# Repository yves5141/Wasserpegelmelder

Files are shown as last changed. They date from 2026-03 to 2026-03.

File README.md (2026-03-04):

# Wasserpegelmelder

## Übersicht

Der **Wasserpegelmelder** ist ein eigenständiges Überwachungssystem zur Frühwarnung vor Hochwasser. Das Gerät kann an Brücken montiert werden und misst kontinuierlich den Wasserstand des Flusses. Bei Überschreiten kritischer Schwellwerte wird automatisch eine Warnung versendet.

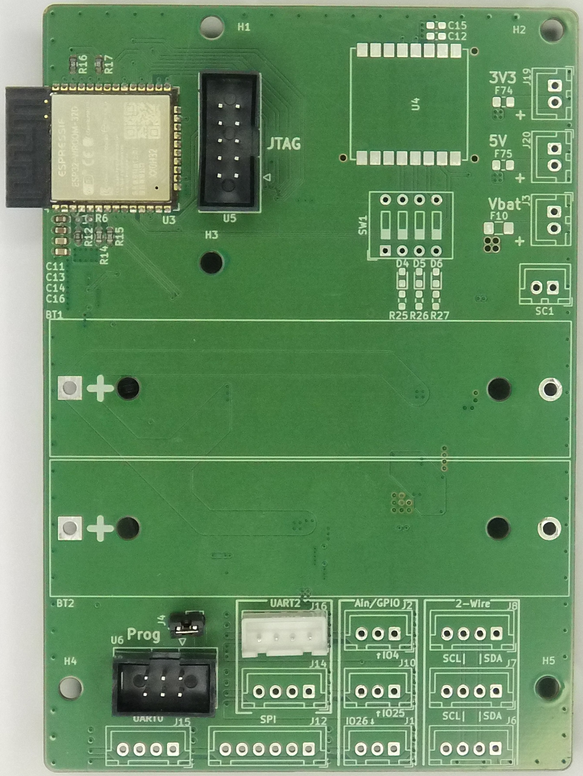
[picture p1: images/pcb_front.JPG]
Gerät von vorne

Gerät von hinten

## Funktionsweise

Der Ultraschallsensor JSN-SR04 misst den Abstand vom Sensor zur Wasseroberfläche. Auf Basis dieses Abstands und der Neigung wird der aktuelle Wasserstand berechnet. Das System überwacht dabei:

- **Wasserstand**: kritisch falls >=95 cm (Hälfte der Flussbett-Tiefe von 190 cm)
- **Anstieg**: kritisch falls >=95 cm/h

Bei Erreichen/Überschreiten dieser Werte wird eine Warnmeldung per Telegram versendet.

## Hardware

Das System basiert auf einem **ESP32-WROOM-32U** und verfügt über:

| Komponente | Beschreibung |
|---|---|
| JSN-SR04T | Ultraschallsensor für Wasserstandsmessung |
| LoRa Ra-02 | Funkmodul für zusätzliche Langstreckenkommunikation |
| CN3791 MPPT | Solarladeregler für 9V Solarzelle (1,17W) |
| TPS63901 | Buck-Boost Regler für 3,3V |
| TPS63802 | Buck-Boost Regler für 5V |
| 18650 | Akkuhalterungen für Akkubetrieb |

### JSN-SR04T

JSN-SR04T

## Betriebsmodi

### Modus 1 - Messung
Das Gerät führt alle 20 Sekunden Messungen durch und geht zwischen den Messungen in den Deep-Sleep Modus, um Strom zu sparen. Keine WLAN-Verbindung wird hergestellt.

### Modus 2 - Fernsteuerung
Alle 5 Minuten wird eine WLAN-Verbindung hergestellt, um auf eingehende Telegram-Befehle zu prüfen und ggf. zu antworten. Anschließend geht das Gerät wieder in den Deep-Sleep Modus.

## Telegram-Befehle

Das Gerät verfügt über einen integrierten Telegram-Bot mit folgenden Befehlen:

| Befehl | Parameter | Ausgabe |
|---|---|---|
| `/meldung` | - | Statusbericht mit aktuellem Wasserstand und Anstiegsgeschwindigkeit |
| `/update` | angehangene FW-Datei | Firmware-Update |

Nur Nachrichten von autorisierten User-IDs werden entgegengenommen und beantwortet.

## Energieeffizienz

Durch Deep-Sleep-Modi und das Abschalten von nicht benötigten Spannungsreglern wird der Stromverbrauch minimiert. Das System ist so ausgelegt, dass es durch die Solarzelle und die 18650 Akkus langfristig eigenständig betrieben werden kann.

## Anwendungsbereich

Das System ist für den Einsatz an einer Brücke gedacht:
- Vorwarnung bei steigendem Wasserstand
- Beobachtung von Anstiegsgeschwindigkeiten
- Langzeitüberwachung des Wasserpegels

Die Installation erfolgt einfach am Geländer mit einer Neigung von ca. 45° zum Lot. Dieser Winkel ergibt sich aus dem Streuwinkel des Sensors zzgl. Toleranz.

## Status und Ausblick

Die Hardwaretests sind abgeschlossen.
Die Softwareimplementierung befindet sich noch in Arbeit.

## Technische Hintergründe

Das Projekt basiert auf einem ESP32-WROOM-32U Modul. Als primäre Kommunikationsschnittstelle dient das integrierte WLAN des ESP32.
Falls lokal kein Hotspot verfügbar ist, kann alternativ auch ein LoRa Funkmodul genutzt werden.
Im Ordner "Hardware" findet sich das KiCAD Projekt für die Hardware.

## 3D Render eines vollbestückten Melders

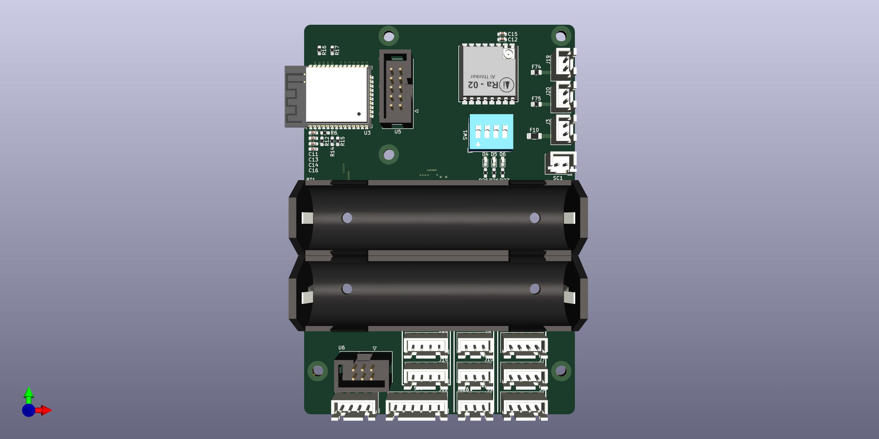
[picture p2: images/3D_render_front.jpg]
3D von vorne

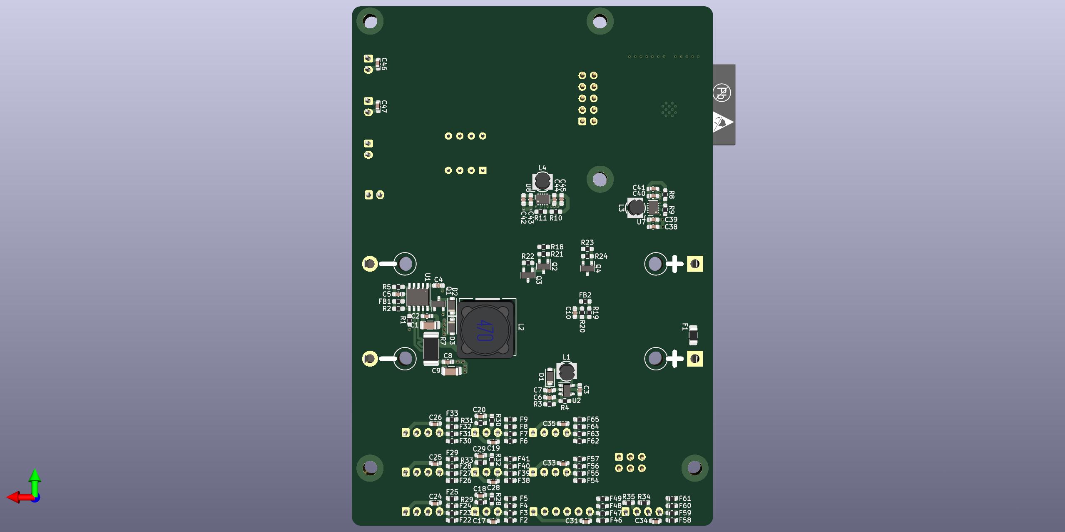
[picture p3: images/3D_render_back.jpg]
3D von hinten


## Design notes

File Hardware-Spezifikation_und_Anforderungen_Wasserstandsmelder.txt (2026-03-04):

Spezifikation Hochwassermelder:

CN3791 MPPT
9V Solarzelle, 1,17W
18650 Akkuhalterung
ESP32-WROOM-32U
LoRa Ra-02 Modul        (keine abschaltung per FET nötig, da digitaler sleep modus)
HC-SR04 Sensor
TPS61041 boostregler für 5V (muss bei nichtnutzung abgeschalten werden zum strom sparen)
TPS63901 Buck-boost regler für 3,3V 400mA

Anmerkungen zum MPPT:

Vmppt = 1,205 * (1+R3 / R4)    -> siehe CN3791 Datenblatt Seite 6
Vmppt von 9V Panel muss ermittelt werden (Vmppt = 0,76 * Voc (open circuit))

D1 sollte SS2040FL sein, da niedriger Leckstrom. ggf. 2-3 Stk. Parallel vorsehen

/CHRG und /DONE müssen jeweils mit einem IO verbunden werden

C1 - laut Datenblatt müssen verschiedene Frequenzen unterdrückt werden, 100nF, 1µF, 100µF Parallel sollten reichen

Anmerkungen zum ESP32-WROOM-32U:

 IOs zur Verfügung

Messung benötigt 2 IOs
LoRa benötigt 4 IOs

Maße Flussbett:

Abstand Brücke <-> Wasser(minimal Stand) ca. 1,9m
Neigungswinkel Sensor zum Lot des Geländers ca. 45,4°
Abstand Sensor <-> Oberkante Brücke ca. ~0,8m

          Sensor
         /
        / |
       /  |
      /   |
     /    ------------- Brücke
    / 45,4°
   /
~~~~~~~~~~~~~~~~~~~~~~~ Wasser

Werte für Anstieg (geschätzt, prüfen ob Referenzwerte vom DWD existieren):

kritischer Anstieg  = Tiefe_Flussbett / Vorwarnzeit
                    = 190cm / 120min
                    = 1,58333cm/min

kritischer Pegel    = Tiefe_Flussbett / 2
                    = 190cm / 2
                    = 95cm

aktuelle Implementierung:

IOs:

IO27 - Ein-/Ausschaltung der Versorgungsspannung Analogmessung und 5V Spannungsregler
IO32 - Ein-/Ausschaltung der 3,3V Versorgungsspannung (externe Geräte)
IO33 - Analogeingang Akkuspannung (Spannungsteiler 51kOhm und 16kOhm)
IO34 - _DONE
IO35 - _CHRG
IO16 - Rx2 (Ultraschallsensor)
IO17 - Tx2 (Ultraschallsensor)
IO18 - Debug LED 1
IO19 - Debug LED 2
IO23 - Debug LED 3

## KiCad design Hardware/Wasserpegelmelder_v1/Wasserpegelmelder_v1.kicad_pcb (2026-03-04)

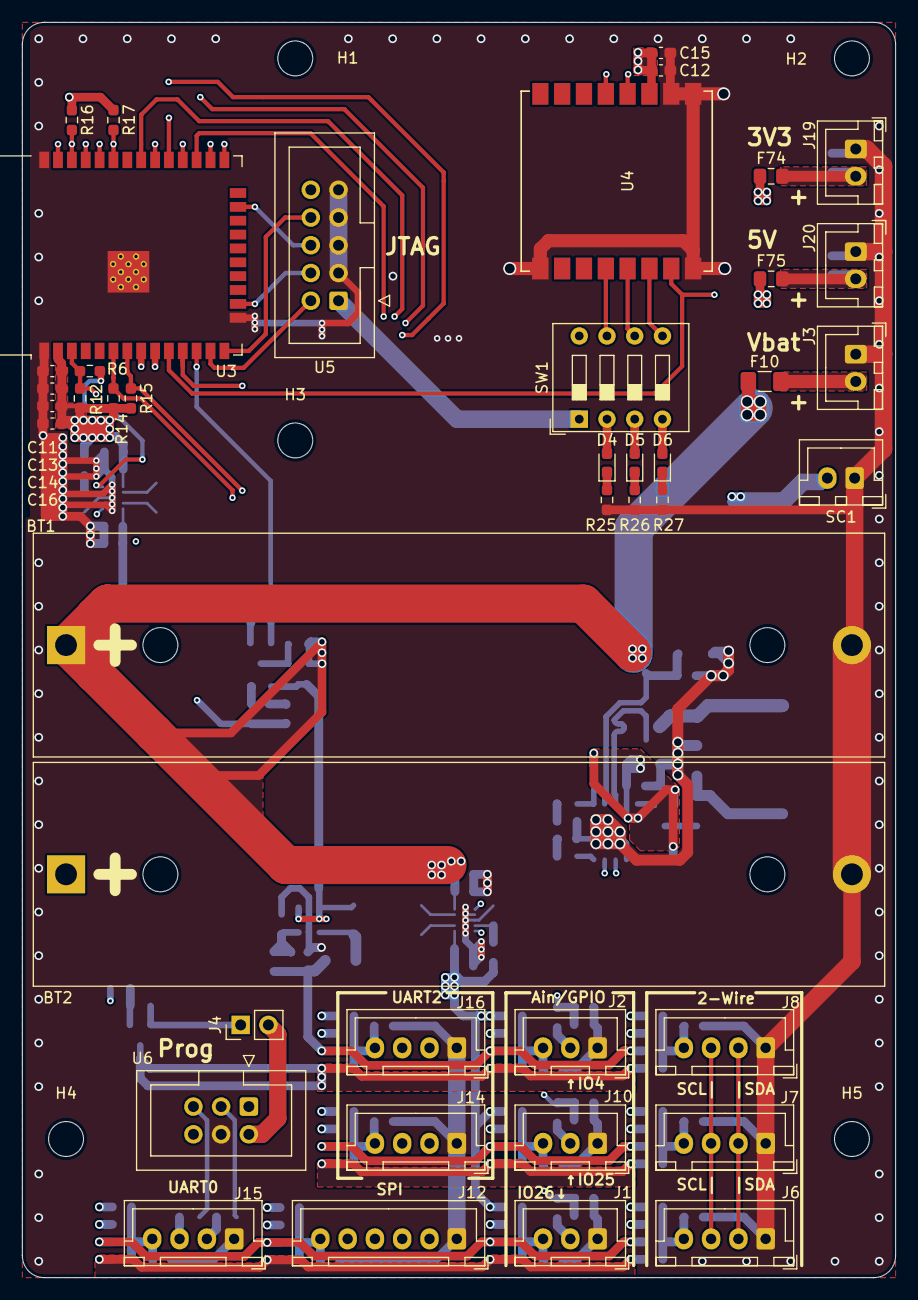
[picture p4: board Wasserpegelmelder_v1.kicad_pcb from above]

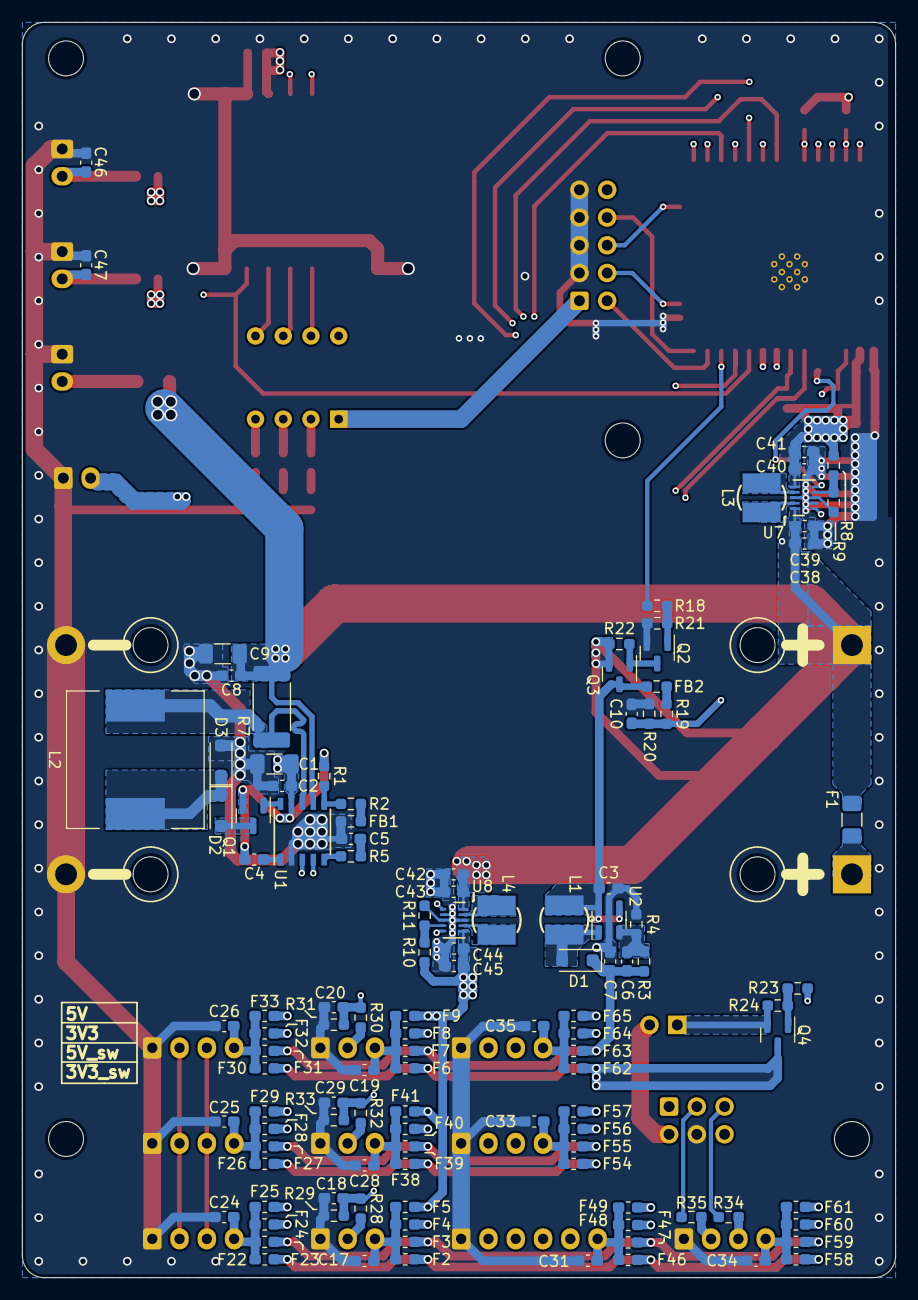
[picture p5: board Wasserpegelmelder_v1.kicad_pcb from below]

Board: 4 copper layers, 80.0 x 115.0 mm, 164 parts (116 on the bottom side), 81 nets.

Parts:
BT1, BT2: Battery_Cell; BatteryHolder_1x_18650
C1, C9: 100µF; C_1206_3216Metric_Pad1.33x1.80mm_HandSolder
C2, C4, C8, C11, C12, C39, C40, C43, C44: 100nF; C_0603_1608Metric_Pad1.08x0.95mm_HandSolder
C3: 10µF; C_0603_1608Metric_Pad1.08x0.95mm_HandSolder
C5: 220nF; C_0603_1608Metric_Pad1.08x0.95mm_HandSolder
C6: 71nF; C_0603_1608Metric_Pad1.08x0.95mm_HandSolder
C7, C13: 1µF; C_0603_1608Metric_Pad1.08x0.95mm_HandSolder
C10, C18, C20, C29: 10nF; C_0603_1608Metric_Pad1.08x0.95mm_HandSolder
C14, C15, C16, C17, C19, C24, C25, C26, C28, C31, C33, C34, C35, C38, C41, C42, C45, C46, C47: 47µF; C_0603_1608Metric_Pad1.08x0.95mm_HandSolder
D1, D2, D3: D_Schottky; D_SOD-123F
D4, D5, D6: LED; LED_0603_1608Metric_Pad1.05x0.95mm_HandSolder
F1: 2A; Fuse_1206_3216Metric_Pad1.42x1.75mm_HandSolder
F2, F3, F4, F5, F6, F7, F8, F9, F22, F23, F24, F25, F26, F27, F28, F29, F30, F31, F32, F33, F38, F39, F40, F41, F46, F47, F48, F49, F54, F55, F56, F57, F58, F59, F60, F61, F62, F63, F64, F65: 100mA; Fuse_0603_1608Metric_Pad1.05x0.95mm_HandSolder
F10: 3A; Fuse_1206_3216Metric_Pad1.42x1.75mm_HandSolder
F74, F75: 100mA; Fuse_0805_2012Metric_Pad1.15x1.40mm_HandSolder
FB1, FB2: FerriteBead; R_0603_1608Metric_Pad0.98x0.95mm_HandSolder
H1, H2, H3, H4, H5: MountingHole; MountingHole_3.2mm_M3
J1, J2, J10: IO_ADC; JST_XH_B3B-XH-A_1x03_P2.50mm_Vertical
J3: BatterySupply; JST_XH_B2B-XH-A_1x02_P2.50mm_Vertical
J4: Prog_Jumper; PinHeader_1x02_P2.54mm_Vertical
J6, J7, J8: IO19_IO23; JST_XH_B4B-XH-A_1x04_P2.50mm_Vertical
J12: SPI_Connector; JST_XH_B6B-XH-A_1x06_P2.50mm_Vertical
J14, J16: UART2; JST_XH_B4B-XH-A_1x04_P2.50mm_Vertical
J15: UART0; JST_XH_B4B-XH-A_1x04_P2.50mm_Vertical
J19, J20: nonSwitchedVoltage; JST_XH_B2B-XH-A_1x02_P2.50mm_Vertical
L1: 10µH; CD32_Inductor
L2: 47µH; L_12x12mm_H8mm
L3, L4: 2.2µH; CD32_Inductor
Q1, Q3, Q4: AO3401A; SOT-23
Q2: AO3400A; SOT-23
R1, R2, R3, R4, R8, R9, R10, R11, R19, R20, R25, R26, R27, R28, R29, R30, R31, R32, R33: R; R_0603_1608Metric_Pad0.98x0.95mm_HandSolder
R5: 120R; R_0603_1608Metric_Pad0.98x0.95mm_HandSolder
R6: 0R; R_0603_1608Metric_Pad0.98x0.95mm_HandSolder
R7: R060; R_2512_6332Metric_Pad1.40x3.35mm_HandSolder
R12: 100k; R_0603_1608Metric_Pad0.98x0.95mm_HandSolder
R14, R15: 1M; R_0603_1608Metric_Pad0.98x0.95mm_HandSolder
R16, R17, R34, R35: 1k; R_0603_1608Metric_Pad0.98x0.95mm_HandSolder
R18, R23: 150R; R_0603_1608Metric_Pad0.98x0.95mm_HandSolder
R21, R22, R24: 10k; R_0603_1608Metric_Pad0.98x0.95mm_HandSolder
SC1: 9V_Solar_Cell; JST_XH_B2B-XH-A_1x02_P2.50mm_Vertical
SW1: SW_DIP_x04; SW_DIP_SPSTx04_Slide_9.78x12.34mm_W7.62mm_P2.54mm
U1: SSOP-10_3.9x4.9mm_P1.00mm
U2: TPS61041DBV; SOT-23-5
U3: ESP32-WROOM-32D
U4: Ai-Thinker-Ra-02; Ai-Thinker-Ra-02-LoRa
U5: IDC-Header_2x05_P2.54mm_Vertical
U6: ESP32_Debugger_Prog_IDC-Header_2x03_P2.54mm_Vertical
U7, U8: TPS63802_DFN-10-1EP_2x3mm_P0.5mm_EP0.64x2.4mm

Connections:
3V3_switch: R23.1, U3.8 (IO32)
3V3_switched: F2.1, F6.1, F22.1, F26.1, F30.1, F38.1, F46.1, F54.1, F58.1, F62.1, Q4.3 (D)
5V_switched: C6.1, C7.1, D1.1 (K), F3.1, F7.1, F23.1, F27.1, F31.1, F39.1, F47.1, F55.1, F59.1, F63.1, R3.1
+3V3: C11.1, C12.1, C13.1, C14.1, C15.1, C16.1, C40.1, C41.1, F4.1, F8.1, F24.1, F28.1, F32.1, F40.1, F48.1, F56.1, F60.1, F64.1, F74.1, J4.1, Q4.2 (S), R8.1, R12.2, R14.2, R15.2, R16.1, R17.1, R24.2, SW1.8, U3.2 (VDD), U4.3 (VDD), U7.6 (Vout)
+5V: C44.1, C45.1, F5.1, F9.1, F25.1, F29.1, F33.1, F41.1, F49.1, F57.1, F61.1, F65.1, F75.1, R10.1, U8.6 (Vout)
+BATT: BT1.1 (+), C8.1, C9.1, C38.1, C39.1, C42.1, C43.1, F1.1, F10.1, Q3.2 (S), R7.2, R22.1, U1.7 (BAT), U7.1 (En), U7.10 (Vin), U8.1 (En), U8.10 (Vin)
/Sense_P: L2.2, R7.1, U1.8 (CSP)
/TPS63802_voltage_regulator1/FB: R10.2, R11.1, U8.4 (FB)
/TPS63802_voltage_regulator/FB: R8.2, R9.1, U7.4 (FB)
/TPS63802_voltage_regulator/PG: R6.2, U7.5 (PG)
Ain_Vbat: C10.1, R19.2, R20.1, U3.9 (IO33)
EN: R6.1, R12.1, U3.3 (EN), U6.1 (EN)
GND: BT1.2 (-), BT2.2 (-), C1.2, C2.2, C3.2, C5.2, C7.2, C8.2, C9.2, C10.2, C11.2, C12.2, C13.2, C14.2, C15.2, C16.2, C17.2, C18.2, C19.2, C20.2, C24.2, C25.2, C26.2, C28.2, C29.2, C31.2, C33.2, C34.2, C35.2, C38.2, C39.2, C40.2, C41.2, C42.2, C43.2, C44.2, C45.2, C46.2, C47.2, D3.2 (A), FB1.2, J1.1, J2.1, J3.1, J6.1, J7.1, J8.1, J10.1, J12.1, J14.1, J15.1, J16.1, J19.1, J20.1, Q2.2 (S), R4.2, R9.2, R11.2, R20.2, R21.2, R25.2, R26.2, R27.2, R29.1, R31.1, R33.1, SC1.1 (+), U1.2 (GND), U2.2 (GND), U3.1 (GND), U3.15 (GND), U3.38 (GND), U3.39 (GND), U4.1 (GND), U4.2 (GND), U4.9 (GND), U4.16 (GND), U5.3 (GND), U5.5 (GND), U5.7 (GND), U5.9 (GND), U6.4 (GND), U7.2 (Mode), U7.3 (AGND), U7.8 (GND), U8.2 (Mode), U8.3 (AGND), U8.8 (GND)
IO0: U3.25 (IO0), U6.6 (IO0)
IO4: C20.1, R30.1, R31.2, U3.26 (IO4), U4.5 (DIO0)
IO5: J12.5, U3.29 (IO5)
IO25: C29.1, R32.1, R33.2, U3.10 (IO25), U4.15 (~NSS)
IO26: C18.1, R28.1, R29.2, U3.11 (IO26), U4.4 (~RESET)
MISO: J12.3, SW1.6, U3.31 (IO19), U4.13 (MISO)
MOSI: J12.4, SW1.5, U3.37 (IO23), U4.14 (MOSI)
unnamed: BT2.1 (+), F1.2
unnamed: C5.1, R5.2
unnamed: D1.2 (A), L1.2, U2.1 (SW)
unnamed: D2.2 (A), Q1.3 (D)
unnamed: D2.1 (K), D3.1 (K), L2.1
unnamed: D4.2 (A), SW1.2
unnamed: D4.1 (K), R25.1
unnamed: D5.2 (A), SW1.3
unnamed: D5.1 (K), R26.1
unnamed: D6.2 (A), SW1.4
unnamed: D6.1 (K), R27.1
unnamed: FB1.1, R2.2
unnamed: FB2.1, R19.1
unnamed: J1.2, R28.2
unnamed: C17.1, F2.2, F3.2, F4.2, F5.2, J1.3
unnamed: J2.2, R30.2
unnamed: C19.1, F6.2, F7.2, F8.2, F9.2, J2.3
unnamed: F10.2, J3.2
unnamed: J4.2, U6.2 (Vcc)
unnamed: C24.1, F22.2, F23.2, F24.2, F25.2, J6.4
unnamed: C25.1, F26.2, F27.2, F28.2, F29.2, J7.4
unnamed: C26.1, F30.2, F31.2, F32.2, F33.2, J8.4
unnamed: J10.2, R32.2
unnamed: C28.1, F38.2, F39.2, F40.2, F41.2, J10.3
unnamed: C31.1, F46.2, F47.2, F48.2, F49.2, J12.6
unnamed: C33.1, F54.2, F55.2, F56.2, F57.2, J14.4
unnamed: J15.2, R35.2
unnamed: J15.3, R34.2
unnamed: C34.1, F58.2, F59.2, F60.2, F61.2, J15.4
unnamed: C35.1, F62.2, F63.2, F64.2, F65.2, J16.4
unnamed: C46.1, F74.2, J19.2
unnamed: C47.1, F75.2, J20.2
unnamed: Q1.1 (G), U1.10 (DRV)
unnamed: C1.1, C2.1, C4.1, Q1.2 (S), R1.1, SC1.2 (-), U1.9 (Vcc)
unnamed: Q2.3 (D), Q3.1 (G), R22.2
unnamed: Q2.1 (G), R18.1, R21.1
unnamed: Q4.1 (G), R23.2, R24.1
unnamed: R5.1, U1.5 (COM)
unnamed: R1.2, R2.1, U1.6 (MPPT)
unnamed: C4.2, U1.1 (VG)
unnamed: C6.2, R3.2, R4.1, U2.3 (FB)
unnamed: SW1.1, U5.1 (VJTAG)
unnamed: L3.1, U7.9 (L1)
unnamed: L3.2, U7.7 (L2)
unnamed: L4.1, U8.9 (L1)
unnamed: L4.2, U8.7 (L2)
Rx0: R34.1, U3.34 (RXD0/IO3), U6.5 (Rx)
Rx2: J14.3, J16.3, U3.27 (IO16)
SCK: J12.2, SW1.7, U3.30 (IO18), U4.12 (SCK)
SCL: J6.3, J7.3, J8.3, R16.2, U3.36 (IO22)
SDA: J6.2, J7.2, J8.2, R17.2, U3.33 (IO21)
TCK: U3.16 (IO13), U5.4 (TCK)
TDI: U3.14 (IO12), U5.8 (TDI)
TDO: U3.23 (IO15), U5.6 (TDO)
TMS: U3.13 (IO14), U5.2 (TMS)
Tx0: R35.1, U3.35 (TXD0/IO1), U6.3 (Tx)
Tx2: J14.2, J16.2, U3.28 (IO17)
Vbat_switch: R18.2, U3.12 (IO27)
Vbat_switched: C3.1, FB2.2, L1.1, Q3.3 (D), U2.4 (EN), U2.5 (VIN)
_CHRG: R15.1, U1.3 (_CHRG), U3.7 (IO35)
_DONE: R14.1, U1.4 (_DONE), U3.6 (IO34)
